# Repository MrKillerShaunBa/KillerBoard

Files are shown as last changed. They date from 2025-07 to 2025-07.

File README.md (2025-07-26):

# KillerBoard
Welcome to KillerBoard, a 65% wireless hot-swappable mechanical keyboard which is made in a sandwich mounted style. It has a 3d printed case, custom PCB and a ProMicro controller for it brains.

I got the motivation to make this when I saw other cool keyboards the people have built for ``#Highway``. Also, I loved making my [Hackpad](https://github.com/MrKillerShaunBa/BajajPad) and wanted to try making something which was bigger, better and wireless of-course.

## Featues

- 65% compact layout
- Wireless, uses Promicro Controller
- ZMK firmware
- Hotswappable
- Brown tactile switches
- 6 deg typing angle
- 3D Printed case and plate
- Sandwich mount

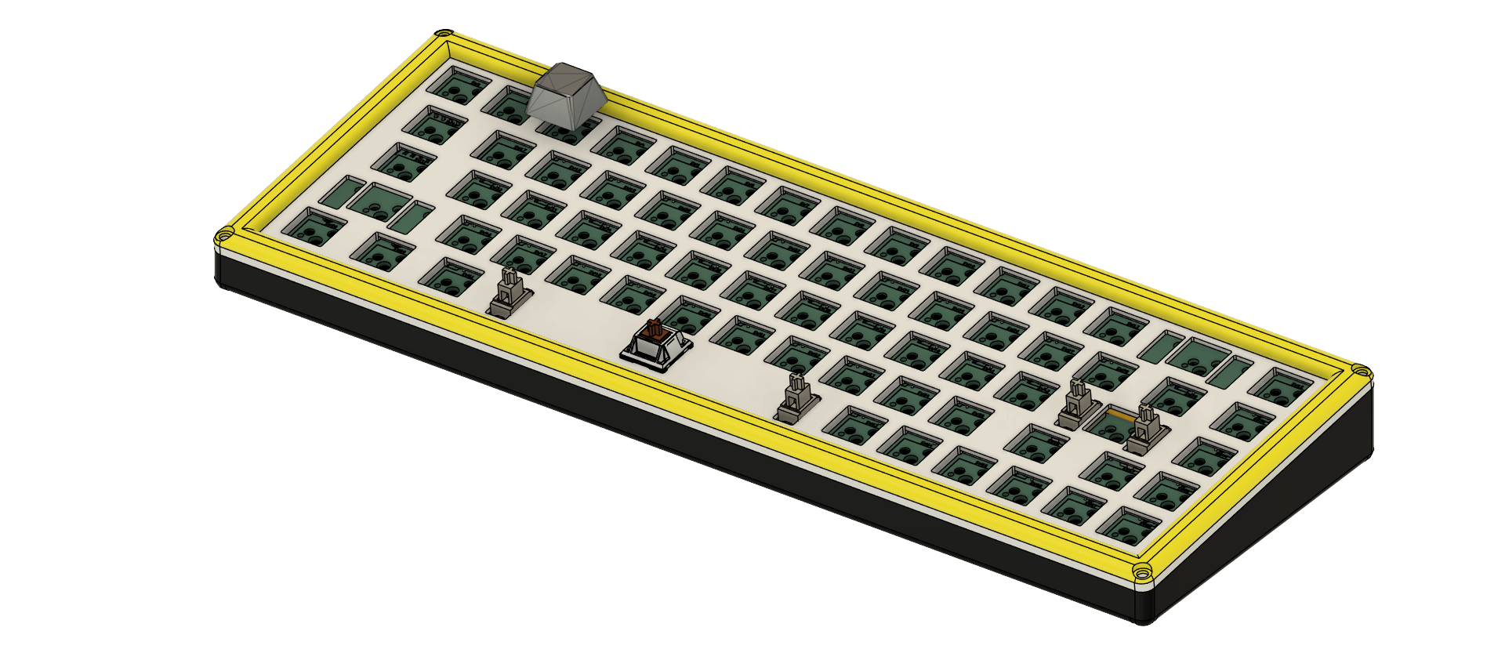
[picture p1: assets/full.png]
full


## CAD

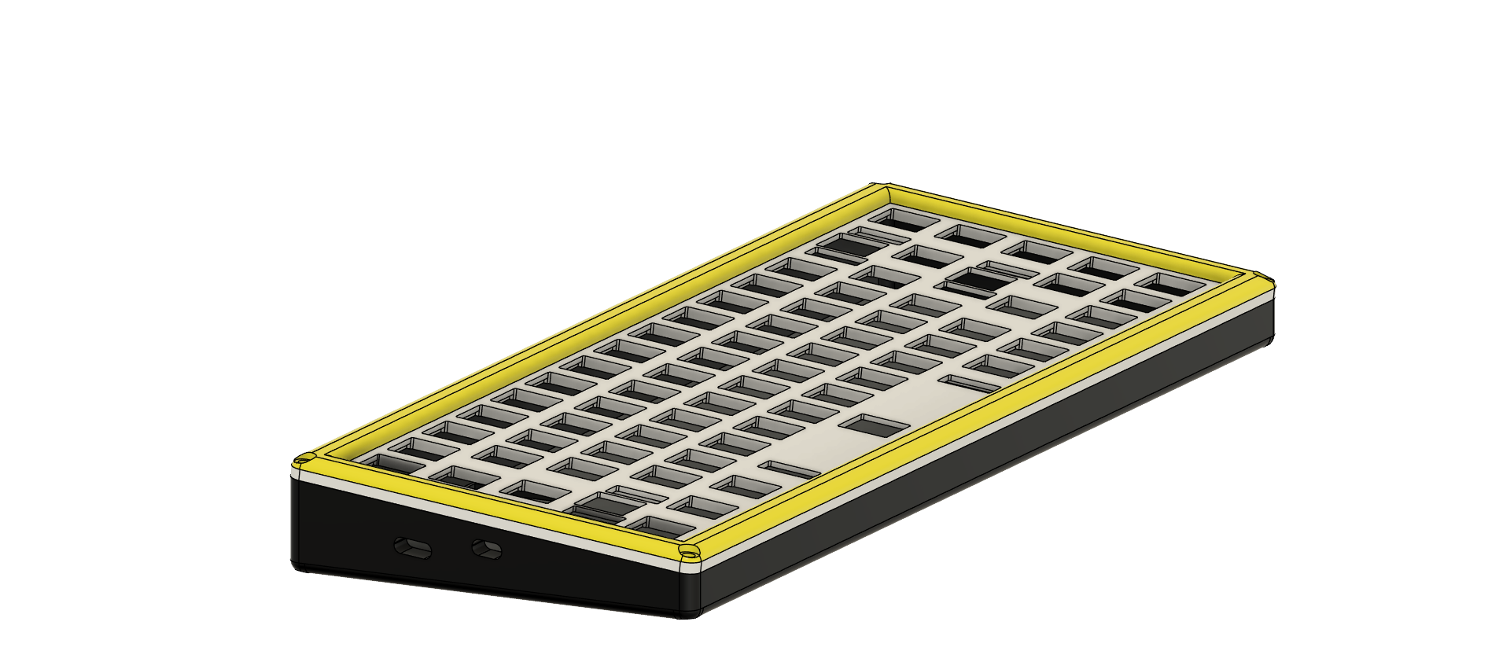
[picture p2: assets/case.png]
case

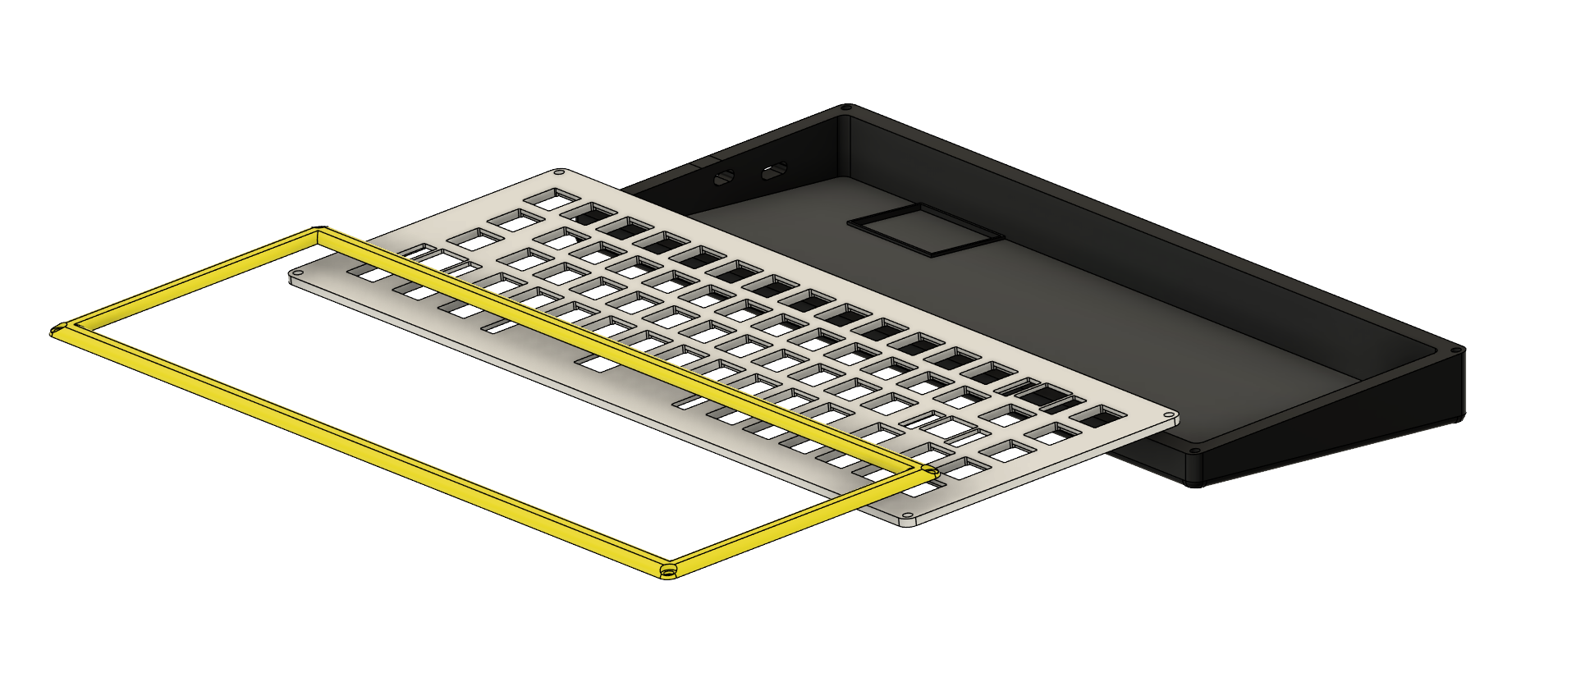
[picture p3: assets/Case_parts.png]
parts

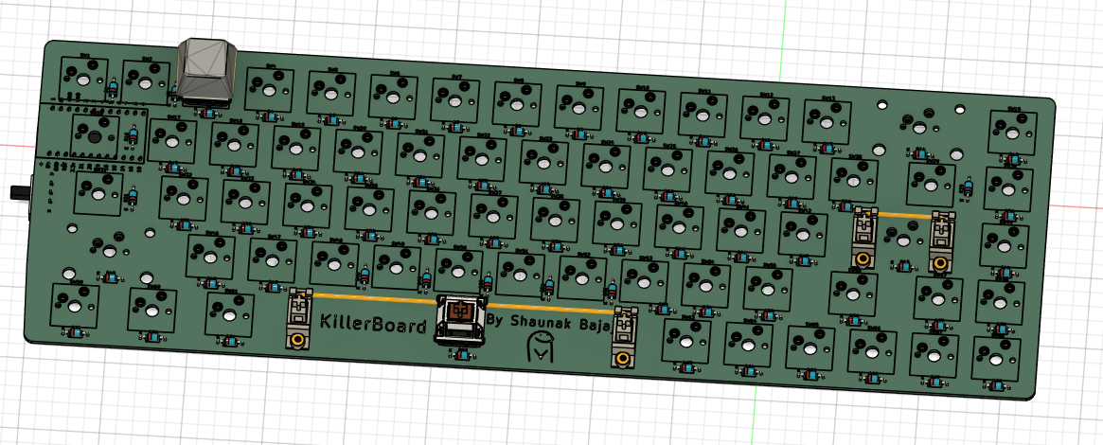
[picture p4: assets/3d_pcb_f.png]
3dF

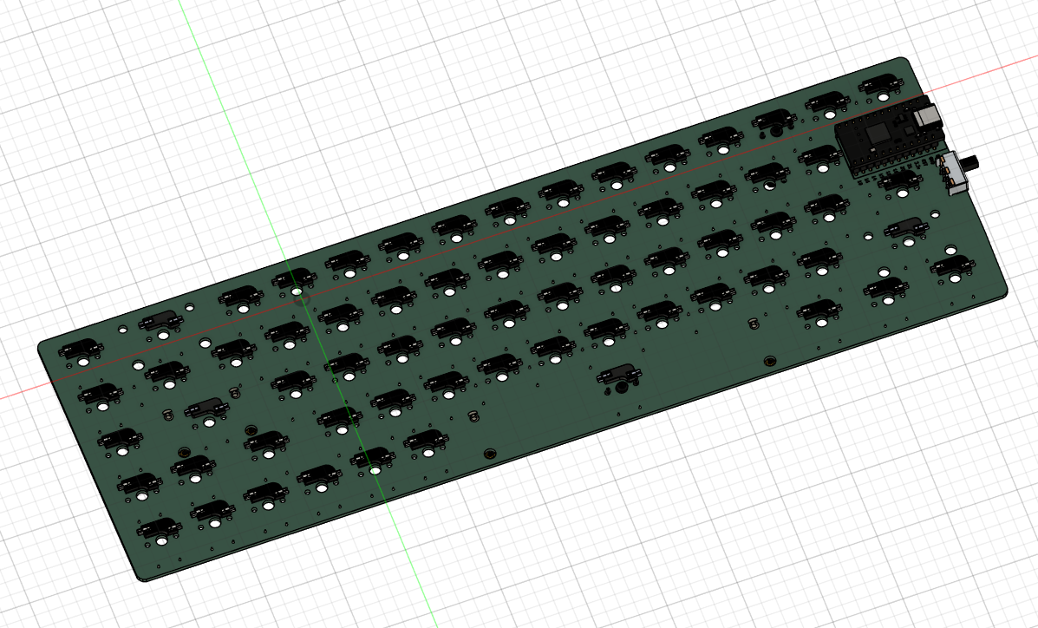
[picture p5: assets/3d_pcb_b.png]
3dB


## PCB

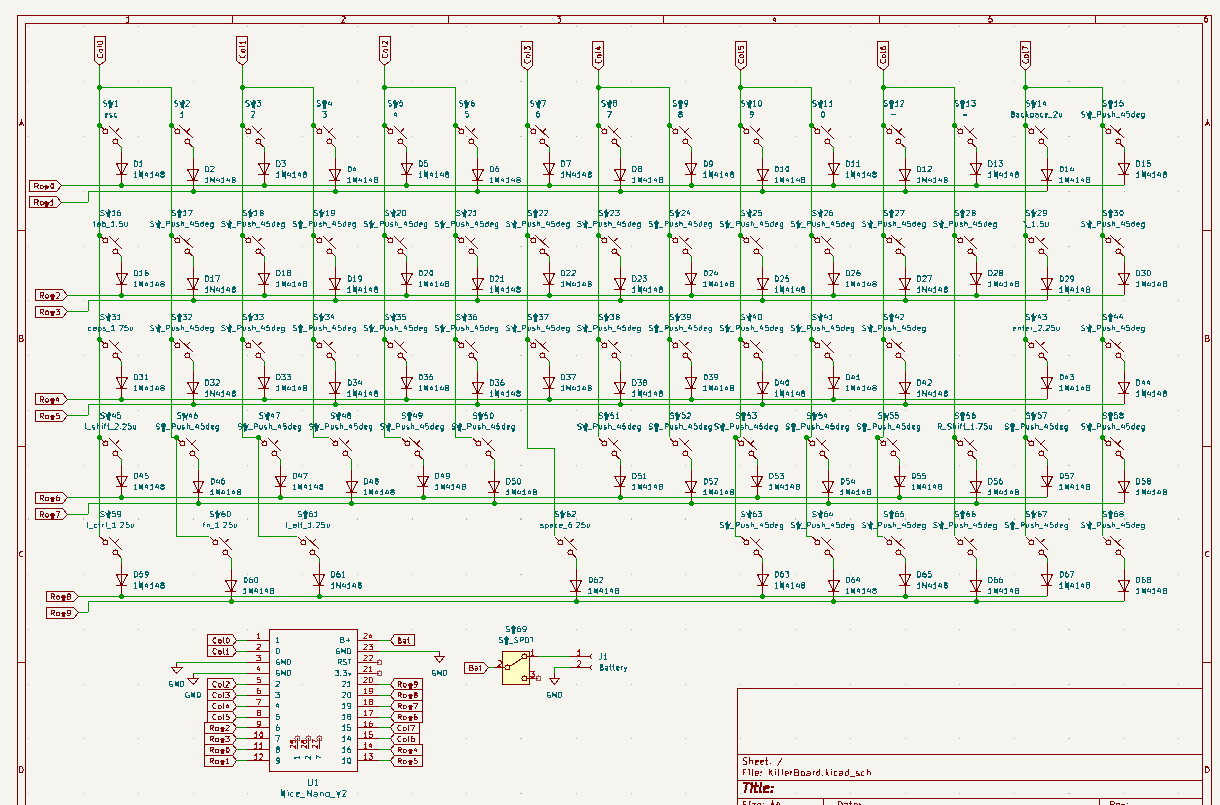
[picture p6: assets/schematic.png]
schematic

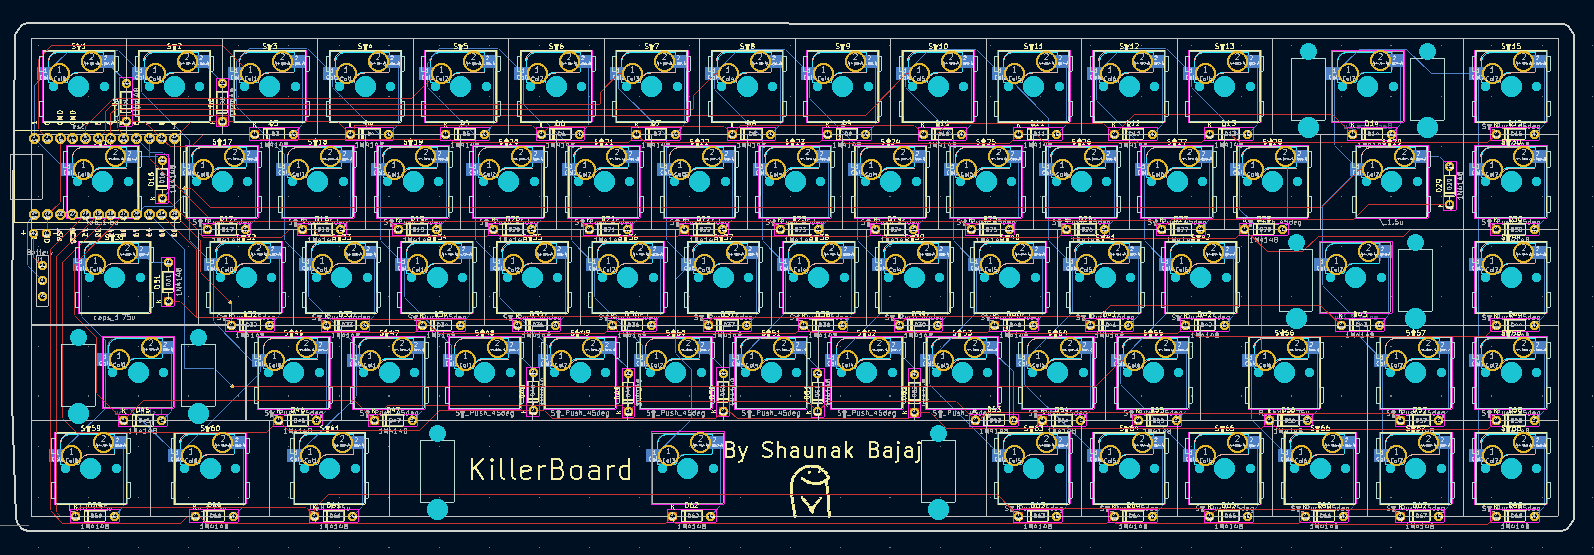
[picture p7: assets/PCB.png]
PCB

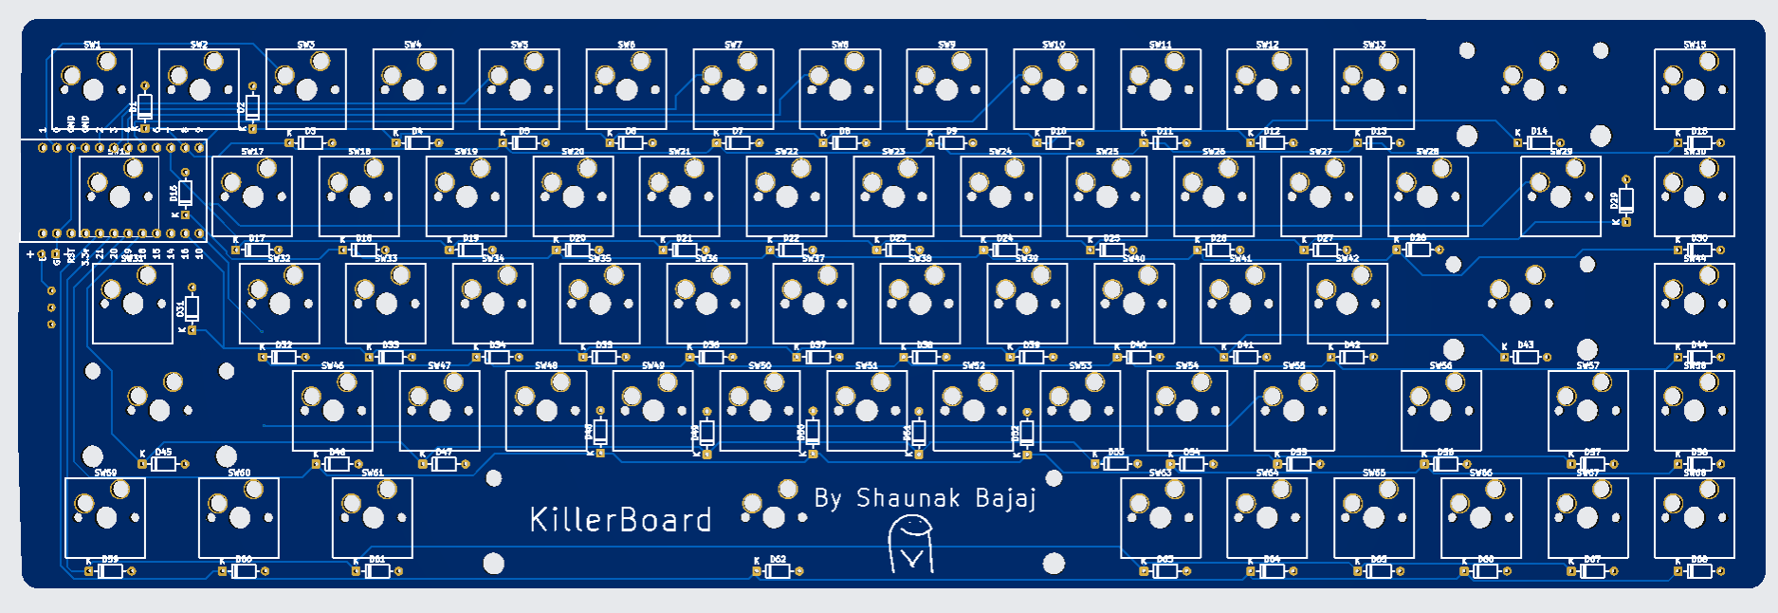
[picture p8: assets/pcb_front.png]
front

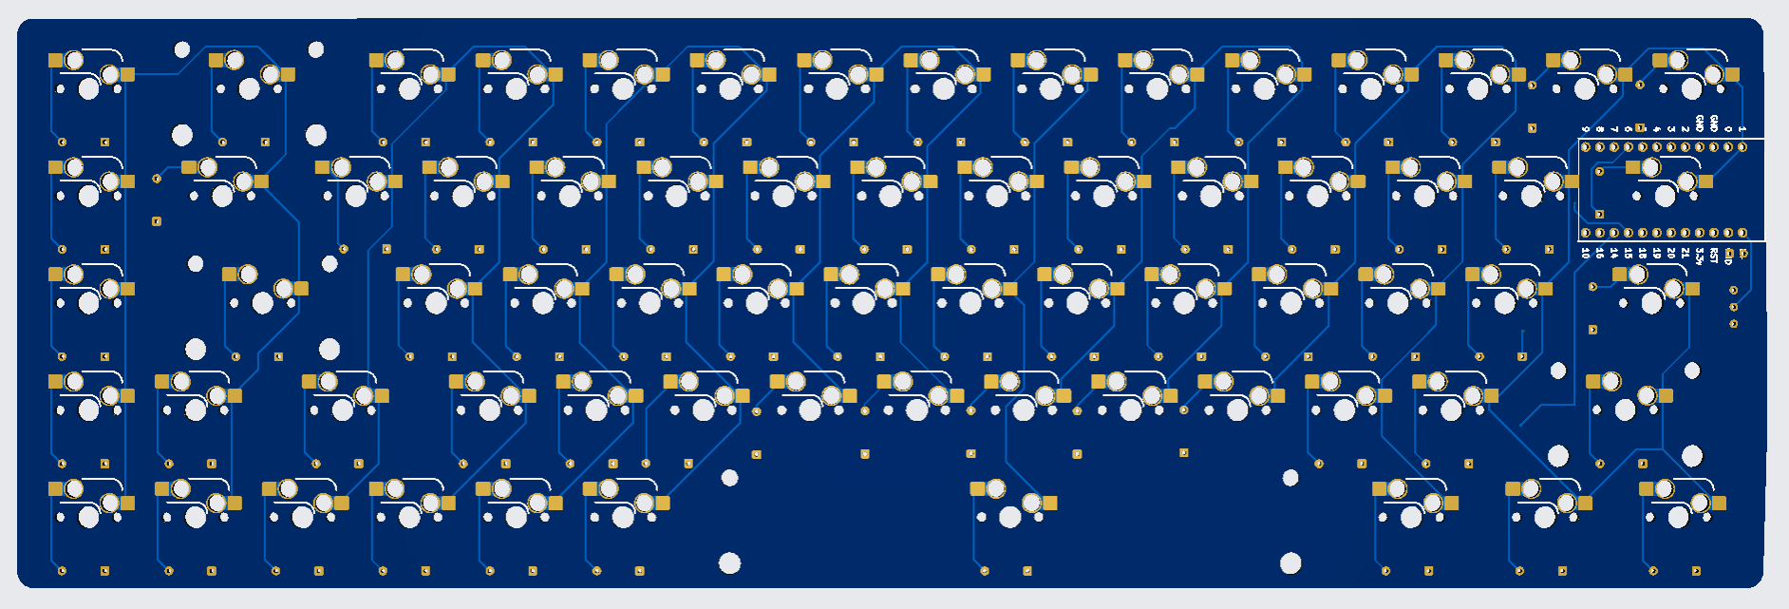
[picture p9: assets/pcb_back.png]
back


## ZMK Keymap 

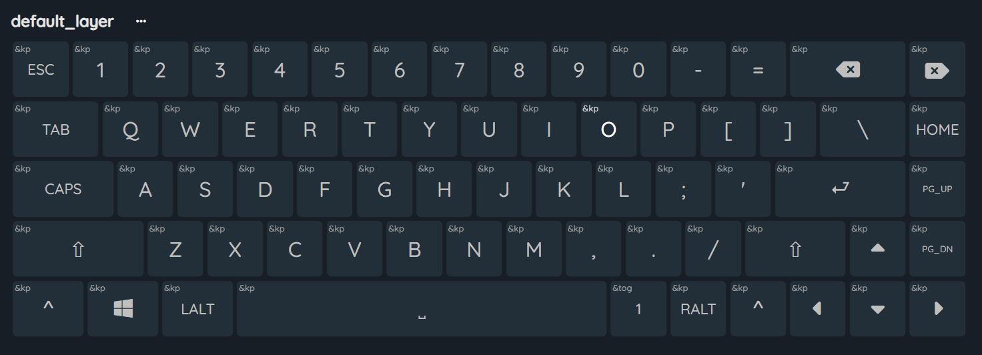
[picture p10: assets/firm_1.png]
layer0

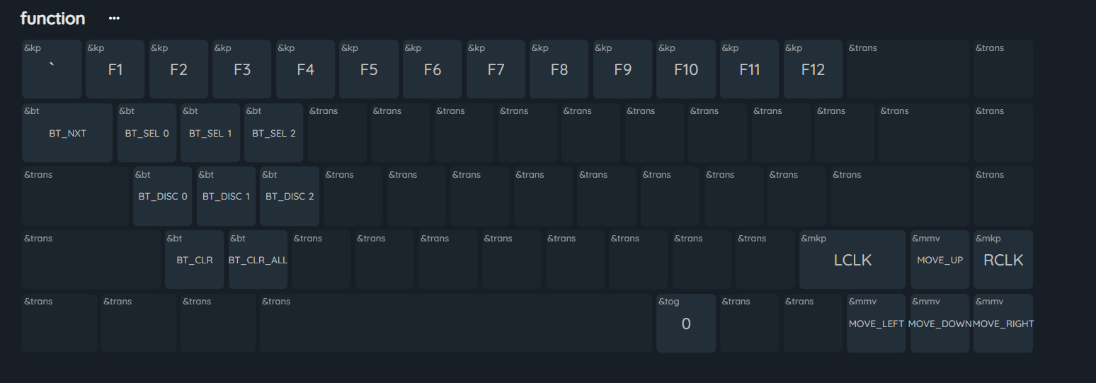
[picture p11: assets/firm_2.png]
layer1


### BOM

| Product | Quantity | Source | Price(INR) | Price($) | Link |
| :-----: | :-----: | :-----: | :-----: | :-----: | :-----: |
| Keycaps | 1 | StacksKB | 1299 | 15.10 | [here](https://stackskb.com/store/veekos-gradient-keycaps-cherry-profile-135-keys/) |
| MX Style Switches | 25*3 | Genesispc | 2400 | 27.91 | [here](https://www.genesispc.in/products/c-equalz-x-tkc-kiwi-switches?variant=43389284286517) |
| Stabilizers | 1 | StacksKB | 1595 | 18.55 | [here](https://stackskb.com/store/durock-smokey-screw-in-stabilizers-v2/) |
| PCB | 5 | JLCPCB | | 11.05 | Includes Shipping (Used Coupon) |
| Case | 1 | Printing Legion | - | ~5 | Only shipping |
| Hotswap Sockets | 10*7 | Meckeys | 536 | 6.23 | [here](https://meckeys.com/shop/accessories/keyboard-accessories/key-switches/kailh-hot-swap-socket/) |
| 1N4148 Diodes | 10*7 | StacksKB | 105 | 1.22 | [here](https://stackskb.com/store/1n4148-through-hole-diode/) |
| ProMicro nRF52840 | 1 | Robu.in | 715 | 8.33| [here](https://robu.in/product/promicro-nrf52840-development-board/) |
| Slide Switch | 1 | Robu.in | 3 | 0.035 | [here](https://robu.in/product/ss-12f21g5-slide-1p2t-angled-switchheight5mm/) |
| Battery | 1 | Robu.in | 256 | 2.97 | [here](https://robu.in/product/wly602540-600mah-3-7v-single-cell-rechargeable-lipo-battery/) |
| PCB receptacle female | 1 | Amazon | 135 | 1.57 | [here](https://amzn.in/d/0Ydhh59) |
| PCB receptacle male | 2 | Robu.in | 68 | 0.79 | [here](https://robu.in/product/361019115sg107601-jiln-2-54x1-9machined-pin-header-1x15p-180-l7-65-upper-pinpoint0-46-bottom-pinpoint0-46-au1u-pps/) |
| Non-slip feet | 100 | Amazon | 130 | 1.51 | [here](https://amzn.in/d/hfOWean) |
| M3x25mm bolts | 12 | Robu | 167 | 1.93 | [here](https://robu.in/product/easymech-set-m3-x-25mm-socket-head-cap-allen-bolt-nut-12-pcs/) |
| M3x15mm bolts | 10 | EDS | 139  | 1.61 | [here](https://store.edsystems.in/thunderbolt-set-of-m3-x-15mm-socket-head-cap-black-(allen)-bolt-and-nut-(10-pcs)) | M3x4mm heatset insert | 25 | Robu | 82 | 0.95 | [here](https://robu.in/product/m3-x-4-mm-brass-heat-set-knurl-threaded-round-insert-nut-25-pcs/) |
| M3x4mm heatset inserts | 25 | Robu | 82 | 0.95 | [here](https://robu.in/product/m3-x-4-mm-brass-heat-set-knurl-threaded-round-insert-nut-25-pcs/) |

Total Cost: About $108-110

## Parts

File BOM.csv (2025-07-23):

Product | Quantity | Source | Price(INR) | Price($) | Link
Keycaps | 1 | StacksKB | 1299 | 15.10 | https://stackskb.com/store/veekos-gradient-keycaps-cherry-profile-135-keys/
MX Style Switches | 25*3 | Genesispc | 2400 | 27.91 | https://www.genesispc.in/products/c-equalz-x-tkc-kiwi-switches?variant=43389284286517
Stabilizers | 1 | StacksKB | 1595 | 18.55 | https://stackskb.com/store/durock-smokey-screw-in-stabilizers-v2/
PCB | 5 | JLCPCB |  | 11.05 | Includes Shipping (Used Coupon)
Case | 1 | Printing Legion | - | ~5 | Only shipping
Hotswap Sockets | 10*7 | Meckeys | 536 | 6.23 | https://meckeys.com/shop/accessories/keyboard-accessories/key-switches/kailh-hot-swap-socket/
1N4148 Diodes | 10*7 | StacksKB | 105 | 1.22 | https://stackskb.com/store/1n4148-through-hole-diode/
ProMicro nRF52840 | 1 | Robu.in | 715 | 8.33 | https://robu.in/product/promicro-nrf52840-development-board/
Slide Switch | 1 | Robu.in | 3 | 0.035 | https://robu.in/product/ss-12f21g5-slide-1p2t-angled-switchheight5mm/
Battery | 1 | Robu.in | 256 | 2.97 | https://robu.in/product/wly602540-600mah-3-7v-single-cell-rechargeable-lipo-battery/
PCB receptacle female | 1 | Amazon | 135 | 1.57 | https://amzn.in/d/0Ydhh59
PCB receptacle male | 2 | Robu.in | 68 | 0.79 | https://robu.in/product/361019115sg107601-jiln-2-54x1-9machined-pin-header-1x15p-180-l7-65-upper-pinpoint0-46-bottom-pinpoint0-46-au1u-pps/
Non-slip feet | 100 | Amazon | 130 | 1.51 | https://amzn.in/d/hfOWean
M3x25mm bolts | 12 | Robu | 167 | 1.93 | https://robu.in/product/easymech-set-m3-x-25mm-socket-head-cap-allen-bolt-nut-12-pcs/
M3x15mm bolts | 10 | EDS | 139 | 1.61 | https://store.edsystems.in/thunderbolt-set-of-m3-x-15mm-socket-head-cap-black-(allen)-bolt-and-nut-(10-pcs)
M3x4mm heatset insert | 25 | Robu | 82 | 0.95 | https://robu.in/product/m3-x-4-mm-brass-heat-set-knurl-threaded-round-insert-nut-25-pcs/
Total Cost: About $105-110

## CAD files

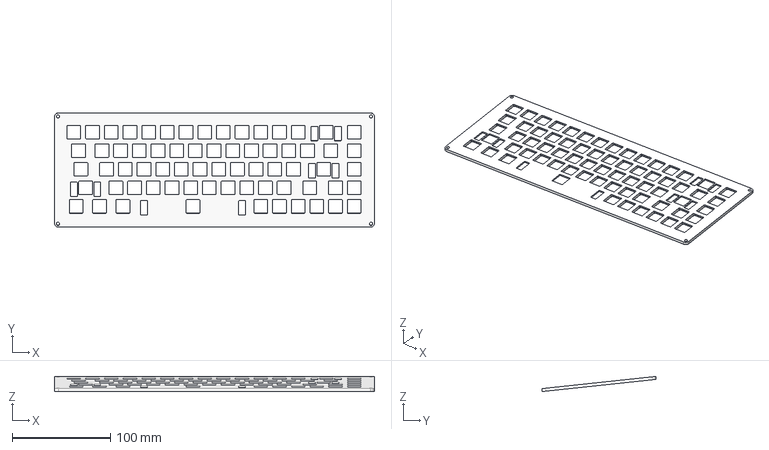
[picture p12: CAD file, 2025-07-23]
Production/Plate.step
326.2 x 116.7 x 15.4 mm

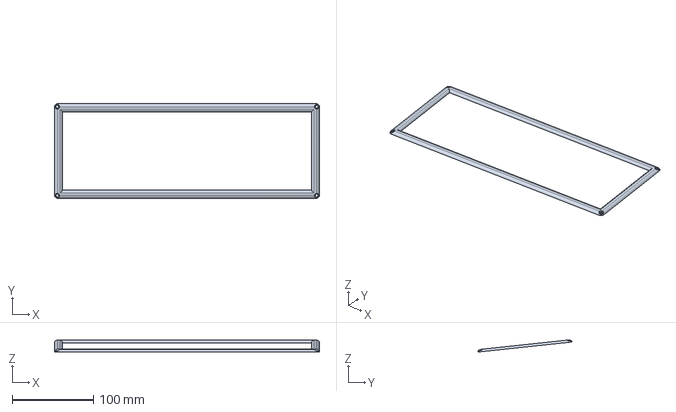
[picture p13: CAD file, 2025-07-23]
Production/Top.step
326.2 x 116.4 x 15.0 mm

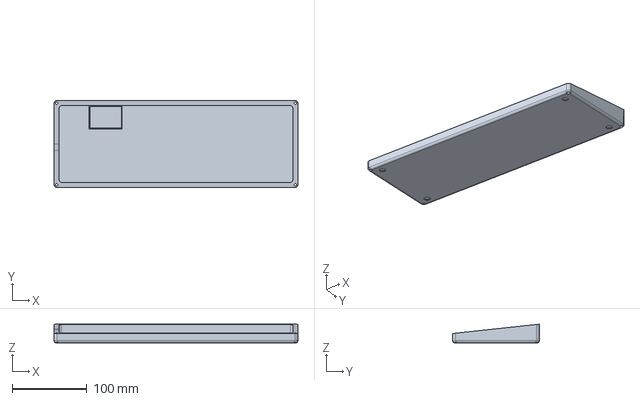
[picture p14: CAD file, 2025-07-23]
Production/Base.step
326.2 x 116.4 x 25.0 mm

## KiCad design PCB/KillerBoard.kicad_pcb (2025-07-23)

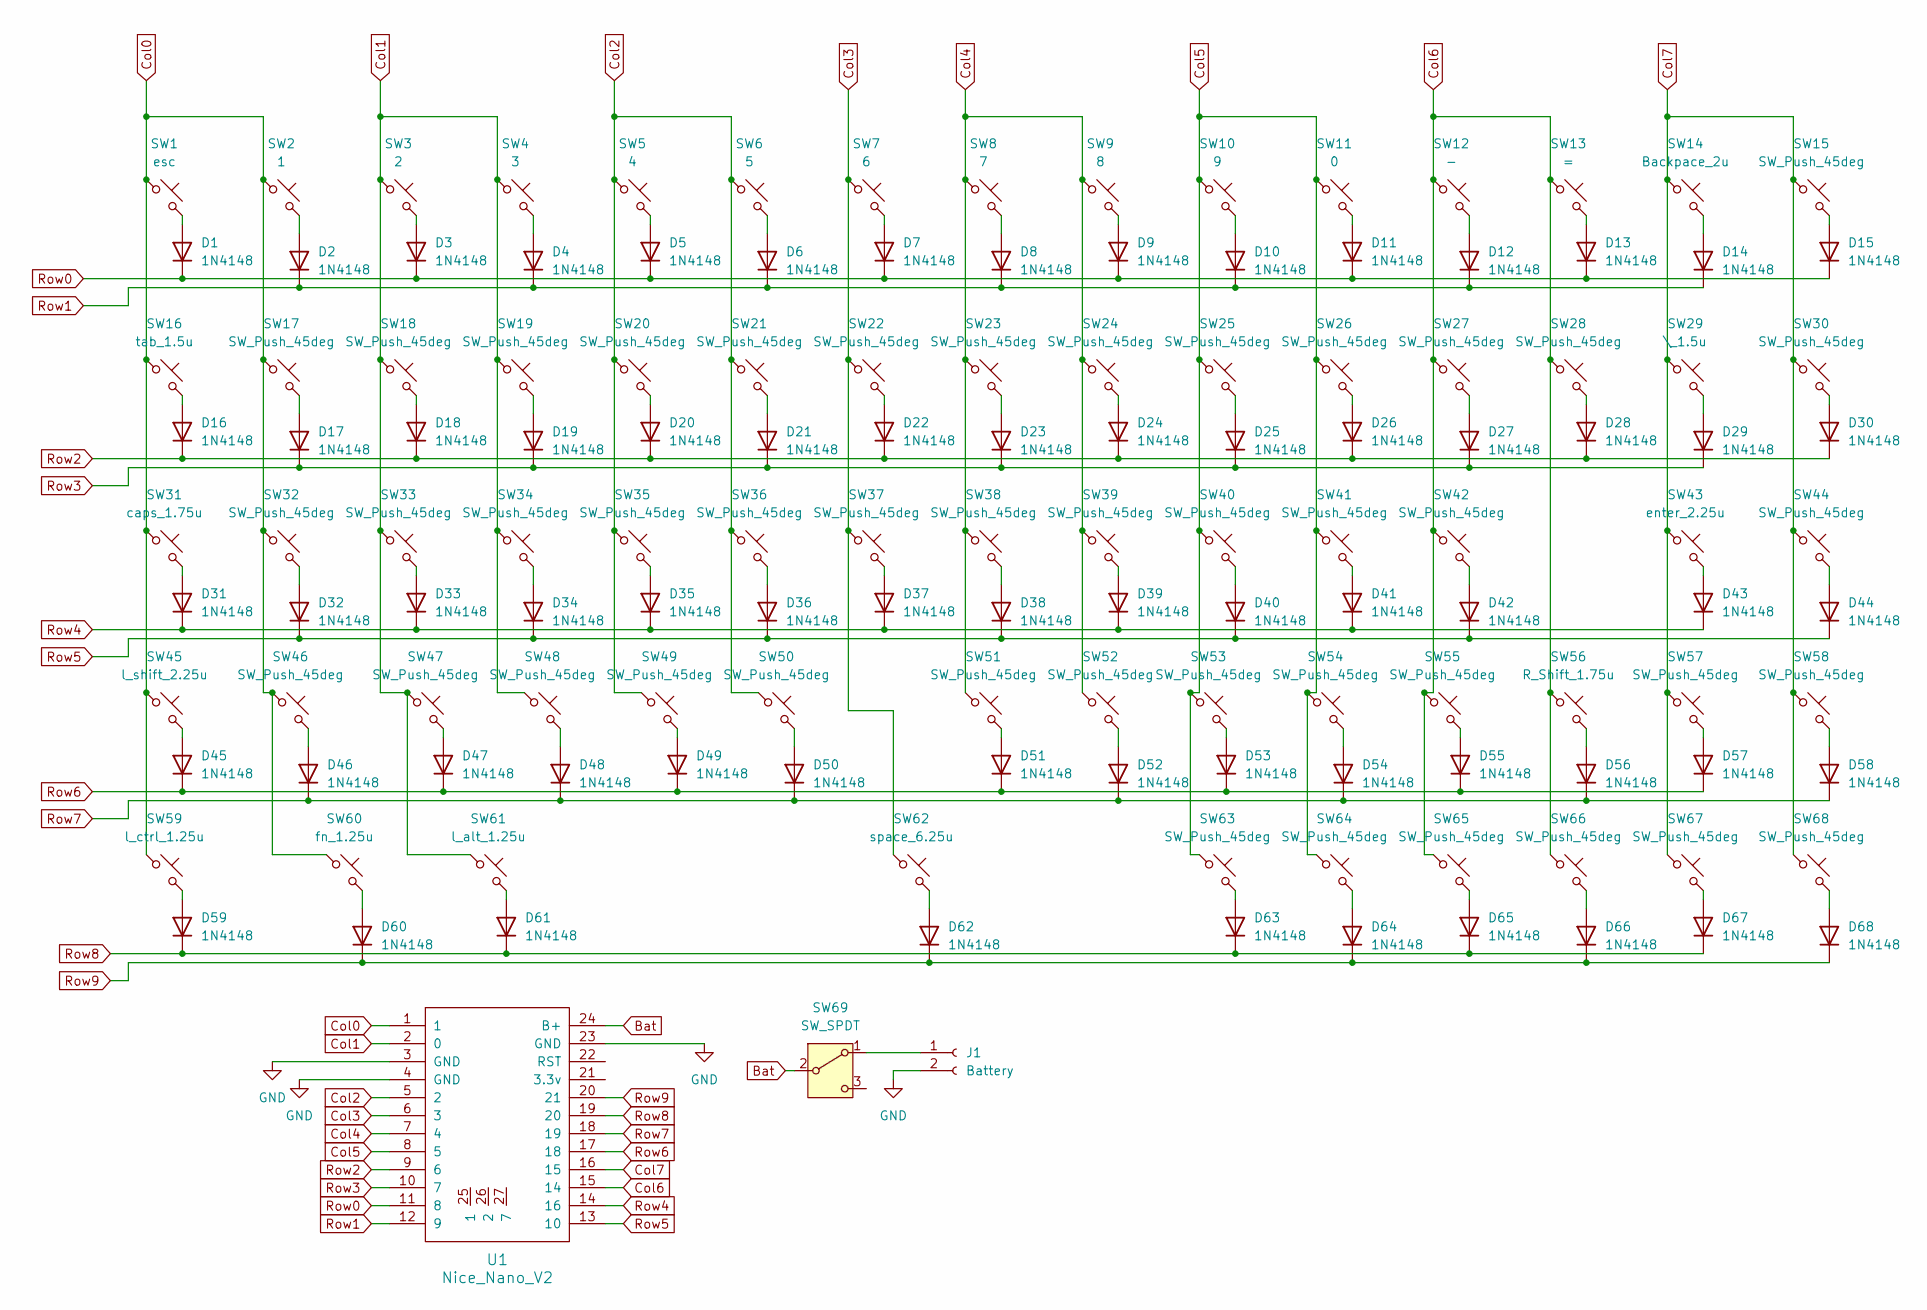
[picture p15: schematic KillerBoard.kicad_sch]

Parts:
D1, D2, D3, D4, D5, D6, D7, D8, D9, D10, D11, D12, D13, D14, D15, D16, D17, D18, D19, D20, D21, D22, D23, D24, D25, D26, D27, D28, D29, D30, D31, D32, D33, D34, D35, D36, D37, D38, D39, D40, D41, D42, D43, D44, D45, D46, D47, D48, D49, D50, D51, D52, D53, D54, D55, D56, D57, D58, D59, D60, D61, D62, D63, D64, D65, D66, D67, D68: 1N4148; D_DO-35_SOD27_P7.62mm_Horizontal
J1: Battery
SW1: esc; Hotswap_MX_Plated_1.00u
SW2: 1; Hotswap_MX_Plated_1.00u
SW3: 2; Hotswap_MX_Plated_1.00u
SW4: 3; Hotswap_MX_Plated_1.00u
SW5: 4; Hotswap_MX_Plated_1.00u
SW6: 5; Hotswap_MX_Plated_1.00u
SW7: 6; Hotswap_MX_Plated_1.00u
SW8: 7; Hotswap_MX_Plated_1.00u
SW9: 8; Hotswap_MX_Plated_1.00u
SW10: 9; Hotswap_MX_Plated_1.00u
SW11: 0; Hotswap_MX_Plated_1.00u
SW12: -; Hotswap_MX_Plated_1.00u
SW13: =; Hotswap_MX_Plated_1.00u
SW14: Backpace_2u; MX_Hotswap_2.00u
SW15, SW17, SW18, SW19, SW20, SW21, SW22, SW23, SW24, SW25, SW26, SW27, SW28, SW30, SW32, SW33, SW34, SW35, SW36, SW37, SW38, SW39, SW40, SW41, SW42, SW44, SW46, SW47, SW48, SW49, SW50, SW51, SW52, SW53, SW54, SW55, SW57, SW58, SW63, SW64, SW65, SW66, SW67, SW68: SW_Push_45deg; Hotswap_MX_Plated_1.00u
SW16: tab_1.5u; Hotswap_MX_Plated_1.50u
SW29: \_1.5u; Hotswap_MX_Plated_1.50u
SW31: caps_1.75u; Hotswap_MX_Plated_1.75u
SW43: enter_2.25u; MX_Hotswap_2.25u
SW45: l_shift_2.25u; MX_Hotswap_2.25u
SW56: R_Shift_1.75u; Hotswap_MX_Plated_1.75u
SW59: l_ctrl_1.25u; Hotswap_MX_Plated_1.25u
SW60: fn_1.25u; Hotswap_MX_Plated_1.25u
SW61: l_alt_1.25u; Hotswap_MX_Plated_1.25u
SW62: space_6.25u; MX_Hotswap_6.25u
SW69: SW_SPDT; Switch_K3-1204D
U1: Nice_Nano_V2

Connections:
Bat: SW69.2 (B), U1.24 (B+)
Col0: SW1.1, SW2.1, SW16.1, SW17.1, SW31.1, SW32.1, SW45.1, SW46.1, SW59.1, SW60.1, U1.1
Col1: SW3.1, SW4.1, SW18.1, SW19.1, SW33.1, SW34.1, SW47.1, SW48.1, SW61.1, U1.2 (0)
Col2: SW5.1, SW6.1, SW20.1, SW21.1, SW35.1, SW36.1, SW49.1, SW50.1, U1.5 (2)
Col3: SW7.1, SW22.1, SW37.1, SW62.1, U1.6 (3)
Col4: SW8.1, SW9.1, SW23.1, SW24.1, SW38.1, SW39.1, SW51.1, SW52.1, U1.7 (4)
Col5: SW10.1, SW11.1, SW25.1, SW26.1, SW40.1, SW41.1, SW53.1, SW54.1, SW63.1, SW64.1, U1.8 (5)
Col6: SW12.1, SW13.1, SW27.1, SW28.1, SW42.1, SW55.1, SW56.1, SW65.1, SW66.1, U1.15 (14)
Col7: SW14.1, SW15.1, SW29.1, SW30.1, SW43.1, SW44.1, SW57.1, SW58.1, SW67.1, SW68.1, U1.16 (15)
GND: J1.2, U1.3 (GND), U1.4 (GND), U1.23 (GND)
unnamed: D1.2 (A), SW1.2
unnamed: D2.2 (A), SW2.2
unnamed: D3.2 (A), SW3.2
unnamed: D4.2 (A), SW4.2
unnamed: D5.2 (A), SW5.2
unnamed: D6.2 (A), SW6.2
unnamed: D7.2 (A), SW7.2
unnamed: D8.2 (A), SW8.2
unnamed: D9.2 (A), SW9.2
unnamed: D10.2 (A), SW10.2
unnamed: D11.2 (A), SW11.2
unnamed: D12.2 (A), SW12.2
unnamed: D13.2 (A), SW13.2
unnamed: D14.2 (A), SW14.2
unnamed: D15.2 (A), SW15.2
unnamed: D16.2 (A), SW16.2
unnamed: D17.2 (A), SW17.2
unnamed: D18.2 (A), SW18.2
unnamed: D19.2 (A), SW19.2
unnamed: D20.2 (A), SW20.2
unnamed: D21.2 (A), SW21.2
unnamed: D22.2 (A), SW22.2
unnamed: D23.2 (A), SW23.2
unnamed: D24.2 (A), SW24.2
unnamed: D25.2 (A), SW25.2
unnamed: D26.2 (A), SW26.2
unnamed: D27.2 (A), SW27.2
unnamed: D28.2 (A), SW28.2
unnamed: D29.2 (A), SW29.2
unnamed: D30.2 (A), SW30.2
unnamed: D31.2 (A), SW31.2
unnamed: D32.2 (A), SW32.2
unnamed: D33.2 (A), SW33.2
unnamed: D34.2 (A), SW34.2
unnamed: D35.2 (A), SW35.2
unnamed: D36.2 (A), SW36.2
unnamed: D37.2 (A), SW37.2
unnamed: D38.2 (A), SW38.2
unnamed: D39.2 (A), SW39.2
unnamed: D40.2 (A), SW40.2
unnamed: D41.2 (A), SW41.2
unnamed: D42.2 (A), SW42.2
unnamed: D43.2 (A), SW43.2
unnamed: D44.2 (A), SW44.2
unnamed: D45.2 (A), SW45.2
unnamed: D46.2 (A), SW46.2
unnamed: D47.2 (A), SW47.2
unnamed: D48.2 (A), SW48.2
unnamed: D49.2 (A), SW49.2
unnamed: D50.2 (A), SW50.2
unnamed: D51.2 (A), SW51.2
unnamed: D52.2 (A), SW52.2
unnamed: D53.2 (A), SW53.2
unnamed: D54.2 (A), SW54.2
unnamed: D55.2 (A), SW55.2
unnamed: D56.2 (A), SW56.2
unnamed: D57.2 (A), SW57.2
unnamed: D58.2 (A), SW58.2
unnamed: D59.2 (A), SW59.2
unnamed: D60.2 (A), SW60.2
unnamed: D61.2 (A), SW61.2
unnamed: D62.2 (A), SW62.2
unnamed: D63.2 (A), SW63.2
unnamed: D64.2 (A), SW64.2
unnamed: D65.2 (A), SW65.2
unnamed: D66.2 (A), SW66.2
unnamed: D67.2 (A), SW67.2
unnamed: D68.2 (A), SW68.2
unnamed: J1.1, SW69.1 (A)
Row0: D1.1 (K), D3.1 (K), D5.1 (K), D7.1 (K), D9.1 (K), D11.1 (K), D13.1 (K), D15.1 (K), U1.11 (8)
Row1: D2.1 (K), D4.1 (K), D6.1 (K), D8.1 (K), D10.1 (K), D12.1 (K), D14.1 (K), U1.12 (9)
Row2: D16.1 (K), D18.1 (K), D20.1 (K), D22.1 (K), D24.1 (K), D26.1 (K), D28.1 (K), D30.1 (K), U1.9 (6)
Row3: D17.1 (K), D19.1 (K), D21.1 (K), D23.1 (K), D25.1 (K), D27.1 (K), D29.1 (K), U1.10 (7)
Row4: D31.1 (K), D33.1 (K), D35.1 (K), D37.1 (K), D39.1 (K), D41.1 (K), D43.1 (K), U1.14 (16)
Row5: D32.1 (K), D34.1 (K), D36.1 (K), D38.1 (K), D40.1 (K), D42.1 (K), D44.1 (K), U1.13 (10)
Row6: D45.1 (K), D47.1 (K), D49.1 (K), D51.1 (K), D53.1 (K), D55.1 (K), D57.1 (K), U1.17 (18)
Row7: D46.1 (K), D48.1 (K), D50.1 (K), D52.1 (K), D54.1 (K), D56.1 (K), D58.1 (K), U1.18 (19)
Row8: D59.1 (K), D61.1 (K), D63.1 (K), D65.1 (K), D67.1 (K), U1.19 (20)
Row9: D60.1 (K), D62.1 (K), D64.1 (K), D66.1 (K), D68.1 (K), U1.20 (21)

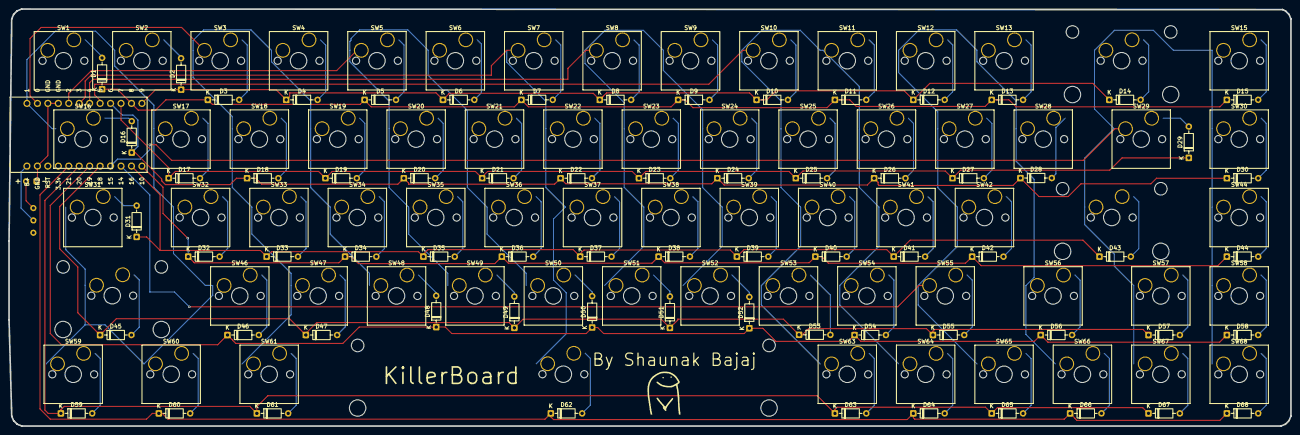
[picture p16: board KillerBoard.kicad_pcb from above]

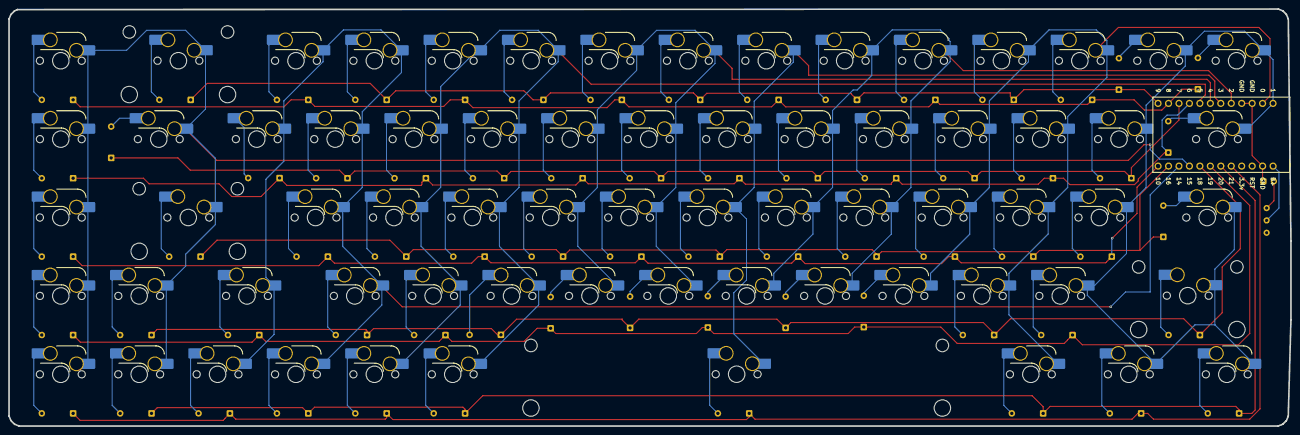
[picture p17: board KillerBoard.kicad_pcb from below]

Board: 2 copper layers, 311.5 x 101.3 mm, 139 parts (2 on the bottom side), 89 nets.

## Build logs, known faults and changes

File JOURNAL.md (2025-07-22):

---
title: "KillerBoard"
author: "Shaunak Bajaj"
description: "Making a mechanical keyboard for #Highway"
created_at: "2025-07-13"
---

### Time Spent Overall: 24.5h

# July 14th: Learned about different keyboard styles and layouts

Read online about mechanical keyboard design and layout. This guide from [Keyboard University](https://www.keyboard.university/100-courses/keyboard-sizes-layouts-gdeby) was extremely helpful. I have decided to go with a 65% because it is compact but perfectly fits my needs.



Finalized this layout


**Total time spent: 2h**

# July 15th: Made a rough BOM and a rough wiring

Researched about key switches and different parts that go into making a keyboard. Made a rough BOM about what is needed.
Also, I am making this one wireless using a nice nano clone!. Made a rough matrix wiring diagram through multiple iterations to meet the number of pins available.





Final layout


**Total time spent: 3.5h**

# July 17th: Made the schematic

Made the schematic in Kicad, connecting so many switches correctly was painful.



**Total time spent: 2.5h**

# July 19th: Finished the PCB

Used keyboard layout plugin to place the components in the PCB editor. Routed everything







**Total time spent: 3h**

# July 20th: Critical mistake and fix, Case

As it is obvious (not in the first glance) that I mistakenly built a mirror image of the keyboard. I tried to use flip and mirror but nothing worked. I had to redo the whole PCB wiring.



Changes the positions of some diodes so that they dont interfere with the stabilizers. Added some silkscreen art.



Added a switch to conserve battery.




Finalised other components like PCB receptacles, battery and power switch and added them to BOM.

Started working on the case, made the bottom. Used the hackpad guide as a reference to make this. One new thing I learned is adding an angle to improve ergonomics.





Made the plate for my keyboard. Designed it as a 3mm plate since 1.5mm is a bit flimsy.



Have made notches for my switches to mount on and have left spaces for the stablizers.



**Total time spent: 6h**

# July 21st: Test fitting

Imported the 3d PCB design to Fusion and test fitted with the base and plate.





Added 3d models of switch, keykap and stabilizers to for a better test fit.



For access to the USB port and On/Off switch I have added cutouts in the base.



**Total time spent: 3h**

# July 22nd: Case top, finishing touches ad firmware

Added a case top with extrusions for my bolt heads.


Used the fillet tool to round the edges. Looks very beautiful now.



Added a small holder in the case bottom for my battery so that it dosent move.



Made small holes in the case bottom to add non slip feet.



Learned about ZMK from various sources like Scotto Keebs and ZMK website. Tried to code the keymap on my own but found it quite overwhelming.
Then I found [this](https://nickcoutsos.github.io/keymap-editor/) great tool which made the process a breeze.

My default layer has the normal keyboard buttons-


The other layer has Functions, Bluetooth settings and mouse control.


**Total time spent: 4.5h**
